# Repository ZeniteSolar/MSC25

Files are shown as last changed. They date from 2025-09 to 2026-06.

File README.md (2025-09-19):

# Módulo Sensor de Corrente(MSC25)

## Visão Geral

Este projeto consiste em uma placa de circuito impresso (PCB) com firmware embarcado, projetada para realizar a leitura de alta precisão de um sensor de corrente de efeito Hall e transmitir os dados através do barramento CAN.

O firmware foi desenvolvido em C para microcontroladores AVR, seguindo uma arquitetura modular, não-bloqueante e orientada por eventos, garantindo robustez e tempo de resposta previsível. O sistema é configurado e compilado utilizando um ambiente `avr-gcc` e `make`.

## Principais Características

* **Microcontrolador:** ATmega328P operando a 16MHz.
* **Comunicação:** Interface CAN Bus 2.0A (11-bit) implementada com controlador dedicado MCP2515 e transceptor MCP2561.
* **Leitura de Sensor:** Interface analógica de alta precisão para sensores de corrente, com condicionamento de sinal.
* **Fonte de Alimentação:** Sistema de alimentação robusto com fonte simétrica isolada para o estágio analógico.
* **Modos de Leitura:** Firmware com modos de operação configuráveis em tempo de compilação:
    * **Modo Média Móvel:** Fornece leituras estáveis, ideal para monitoramento de estado.
    * **Modo Instantâneo:** Fornece a última leitura bruta, ideal para captura de picos e transientes de corrente.
* **Arquitetura de Firmware:** Modular, baseada em máquina de estados e interrupções de hardware para tarefas periódicas.

## Detalhes do Hardware

O hardware foi projetado para garantir a integridade do sinal e a robustez da comunicação.

### Fonte de Alimentação

A placa recebe uma tensão de entrada de 18V, que é regulada internamente para os domínios digitais e analógicos:

* **+12V:** Gerado por um regulador LM7812 para alimentar periféricos e o estágio de amplificação.
* **+5V:** Gerado por um regulador LM7805 para alimentar o microcontrolador ATmega328P e o controlador CAN MCP2515.

#### Fonte Simétrica Isolada (±15V)

Para a correta polarização do sensor de corrente e do circuito de condicionamento analógico, foi implementada uma fonte simétrica de ±15V. Esta etapa utiliza dois conversores DC/DC isolados do tipo **PDSE1-S5-S15-S**. A partir da entrada de +5V, cada conversor gera uma tensão de saída isolada (+15V e -15V, respectivamente). A isolação galvânica garante que ruídos do barramento de alimentação principal não interfiram na precisão das medições analógicas.

### Sensor e Condicionamento de Sinal

O circuito foi projetado para interfacear com um sensor de corrente de efeito Hall, como o **SECOHR 200SCV**.

O sinal de saída do sensor é processado por um circuito de condicionamento baseado no amplificador operacional **LM324**. Este estágio tem a função de amplificar e deslocar o nível de tensão (offset) do sinal, ajustando-o para a faixa de leitura do conversor Analógico-Digital (ADC) do ATmega328P (0-5V). O resultado é um sinal robusto e centralizado, que permite a medição de correntes tanto positivas quanto negativas.

## Detalhes do Firmware

O firmware é escrito em C puro (padrão gnu99) e compilado com `avr-gcc`.

### Arquitetura

A lógica principal é controlada por uma máquina de estados (`machine.c`) que é executada em uma frequência fixa de 100 Hz, controlada pela interrupção do `Timer2`. A leitura do ADC é desacoplada da lógica principal, sendo disparada pelo `Timer0` a uma frequência de 1000 Hz e processada através de interrupções (`ISR(ADC_vect)`), garantindo que as amostragens ocorram de forma consistente. A comunicação entre a rotina de interrupção e o laço principal é feita através de flags voláteis para evitar condições de corrida.

### Módulos Principais

* **`main`**: Ponto de entrada, inicialização dos periféricos e laço principal.
* **`adc`**: Gerencia a configuração do ADC, o disparo por timer, a rotina de interrupção e as funções de processamento (média e leitura instantânea). Inclui um placeholder para **linearização** do sensor.
* **`machine`**: Contém a máquina de estados principal e a lógica de aplicação.
* **`can_app`**: Camada de aplicação do protocolo CAN. Responsável por montar e enviar as mensagens nos intervalos corretos.
* **`conf`**: Arquivo de cabeçalho central para todas as configurações de compilação, como ativação de módulos e seleção de modos de operação.

## Protocolo CAN

A placa se identifica na rede CAN e transmite duas mensagens principais.

* **Nome do Módulo:** `MSC25_1`
* **Assinatura (Signature):** `195` (0xC3)

| Mensagem | ID (Hex) | ID (Dec) | Frequência | Tamanho | Payload |
| :--- | :---: | :---: | :---: | :---: | :--- |
| **State** | `0x79` | 121 | 1 Hz | 3 Bytes | `[Assinatura, Estado, Erro]` |
| **Measurements** | `0xF0` | 240 | 10 Hz | 3 Bytes | `[Assinatura, Corrente_L, Corrente_H]` |

## Ambiente de Desenvolvimento

* **Toolchain:** `avr-gcc`, `avr-libc`, `make`
* **Programador:** `avrdude` (configurado para `arduino`)
* **Biblioteca Principal:** `avr-can-lib` (deve estar presente na pasta `lib/`)

## Como Compilar e Gravar

1.  **Preparar Bibliotecas:** Execute o script para compilar a `avr-can-lib` e baixar o `can_ids.h` mais recente.
    ```bash
    ./makelibs.sh
    ```

2.  **Compilar o Projeto:** Use o comando `make` para compilar todo o código-fonte.
    ```bash
    make
    ```

3.  **Limpar o Projeto:** Para apagar os arquivos compilados.
    ```bash
    make clean
    ```

4.  **Gravar na Placa:** Para compilar (se necessário) e gravar o firmware no microcontrolador.
    ```bash
    make flash
    ```
5.  **Fazer Tudo (Limpar, Compilar, Gravar e Monitorar):**
    ```bash
    ./up.sh
    ```

 ## Precisa adicionar ao can_ids.h
  ```
 // MSC25_1 - Módulo Sensor de Corrente (Sua Nova Placa)
#define CAN_SIGNATURE_MSC25_1 195
// MSC25_1 - STATE - Module state report
#define CAN_MSG_MSC25_1_STATE_ID 121
#define CAN_MSG_MSC25_1_STATE_LENGTH 3
#define CAN_MSG_MSC25_1_STATE_FREQUENCY 1
#define CAN_MSG_MSC25_1_STATE_SIGNATURE_BYTE 0 //<!" Senders signature
#define CAN_MSG_MSC25_1_STATE_STATE_BYTE 1     //<!" State code
#define CAN_MSG_MSC25_1_STATE_ERROR_BYTE 2     //<!" Error code

// MSC25_1 - MEASUREMENTS - Current measurements from the sensor
#define CAN_MSG_MSC25_1_MEASUREMENTS_ID 240
#define CAN_MSG_MSC25_1_MEASUREMENTS_LENGTH 3
#define CAN_MSG_MSC25_1_MEASUREMENTS_FREQUENCY 10
#define CAN_MSG_MSC25_1_MEASUREMENTS_SIGNATURE_BYTE 0    //<!" Senders signature
#define CAN_MSG_MSC25_1_MEASUREMENTS_CURRENT_L_BYTE 1    //<!" Average current, byte low
#define CAN_MSG_MSC25_1_MEASUREMENTS_CURRENT_H_BYTE 2    //<!" Average current, byte high
```

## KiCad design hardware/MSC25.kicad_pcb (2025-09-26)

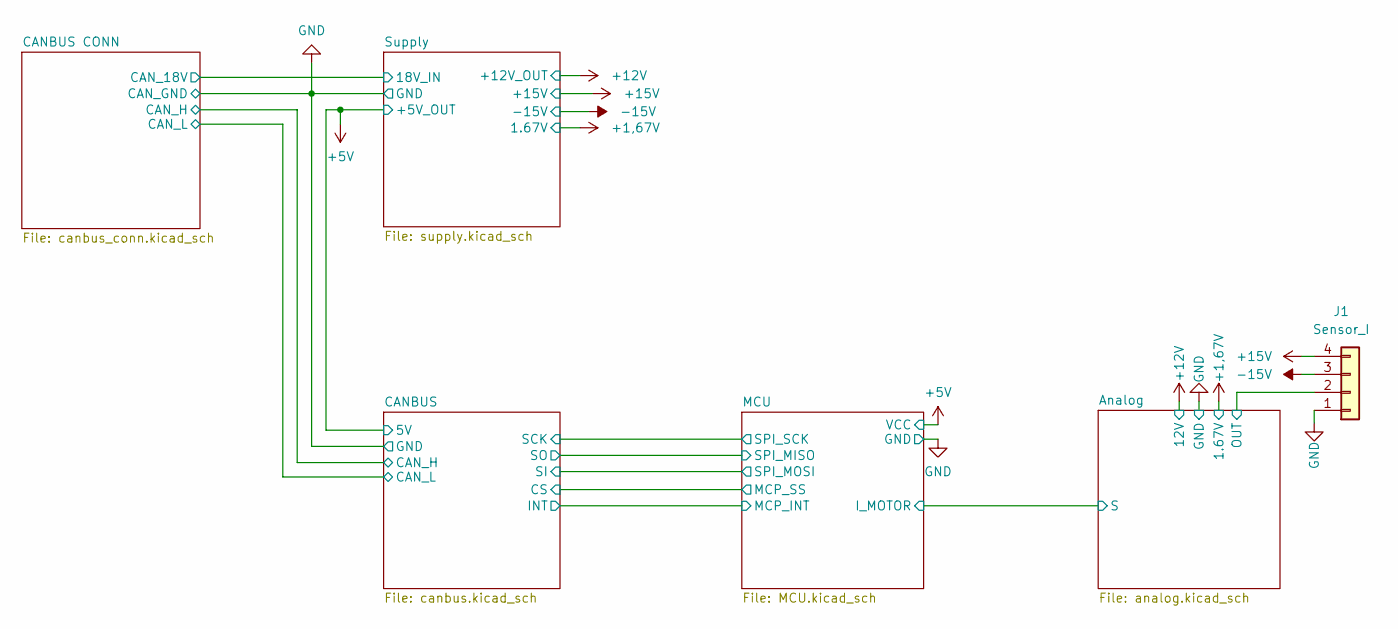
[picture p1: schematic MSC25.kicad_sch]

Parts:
J1: Sensor_I; PinHeader_1x04_P2.54mm_Vertical

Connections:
+15V: J1.4; also elsewhere on the board
-15V: J1.3; also elsewhere on the board
/Analog/OUT: J1.2; also elsewhere on the board
GND: J1.1; also elsewhere on the board

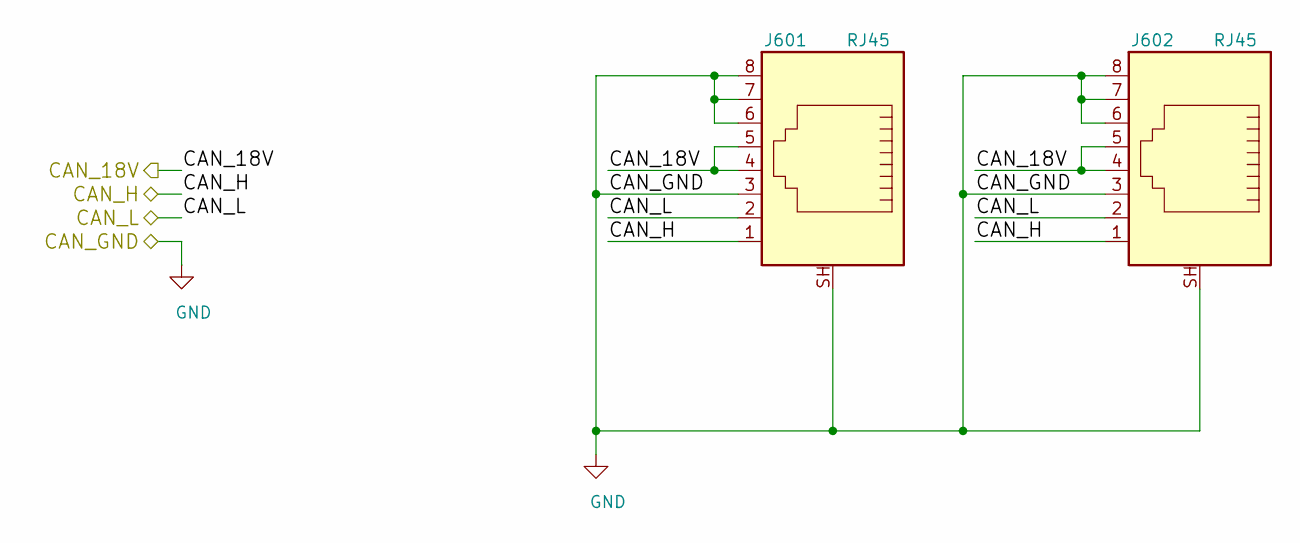
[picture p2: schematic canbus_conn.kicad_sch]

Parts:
J601, J602: RJ45; RJ45_YH59_01

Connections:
/CANBUS CONN/CAN_18V: J601.4, J601.5, J602.4, J602.5; also elsewhere on the board
/CANBUS CONN/CAN_H: J601.1, J602.1; also elsewhere on the board
/CANBUS CONN/CAN_L: J601.2, J602.2; also elsewhere on the board
GND: J601.3, J601.6, J601.7, J601.8, J601.SH, J602.3, J602.6, J602.7, J602.8, J602.SH; also elsewhere on the board

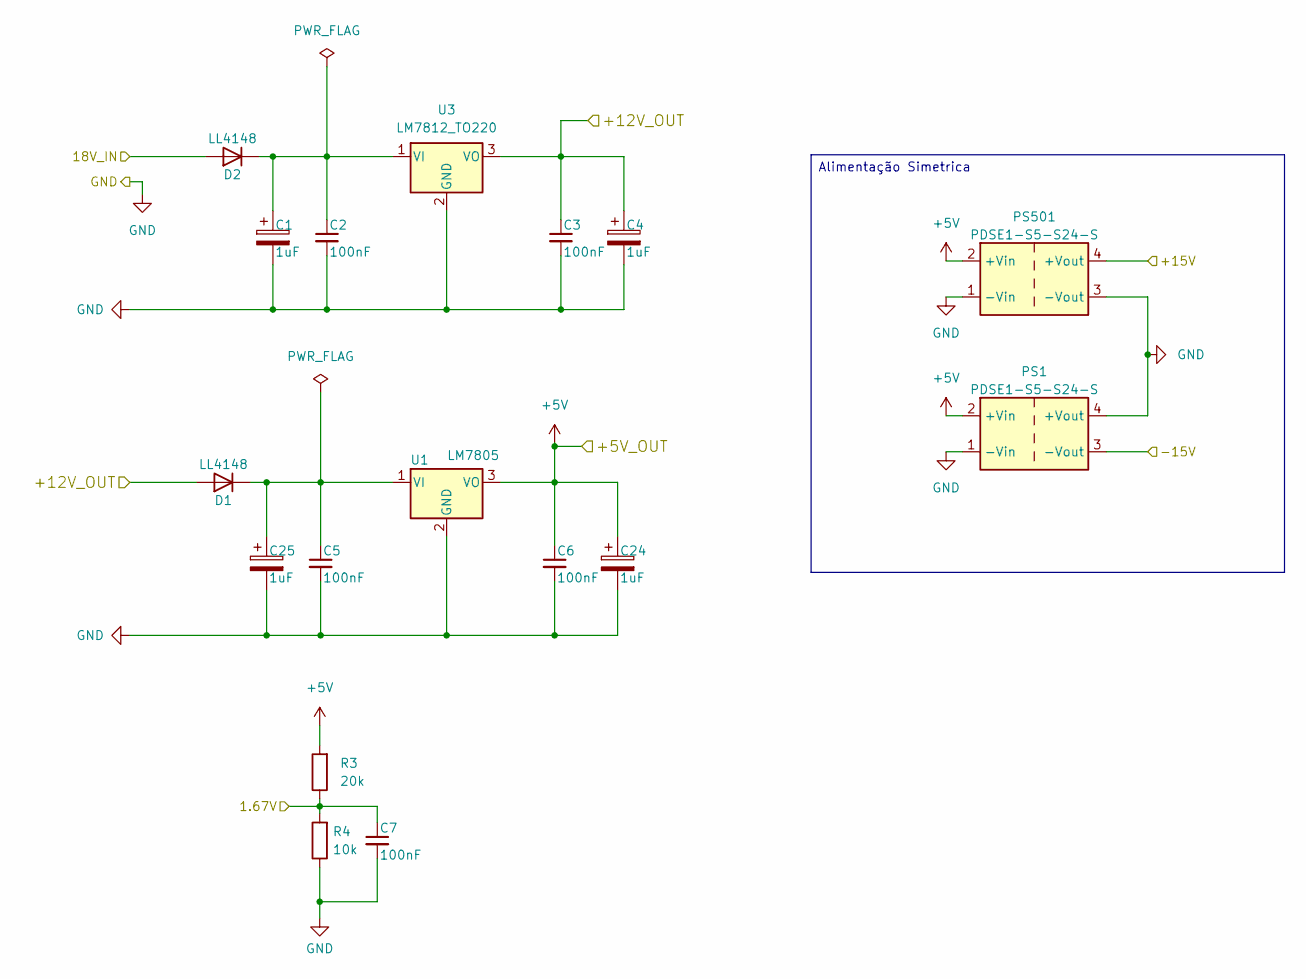
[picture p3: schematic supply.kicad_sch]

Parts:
C1, C4, C24, C25: 1uF; CP_EIA-6032-15_Kemet-U_HandSolder
C2, C3, C5, C6, C7: 100nF; C_0805_2012Metric_Pad1.18x1.45mm_HandSolder
D1, D2: LL4148; D_MiniMELF_Handsoldering
PS1, PS501: PDSE1-S5-S24-S; Converter_DCDC_Murata_MEE3SxxxxSC_THT
R3: 20k; R_0805_2012Metric_Pad1.20x1.40mm_HandSolder
R4: 10k; R_0805_2012Metric_Pad1.20x1.40mm_HandSolder
U1: LM7805; TO-220-3_Horizontal_TabDown
U3: LM7812_TO220; TO-220-3_Horizontal_TabDown

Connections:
+1,67V: C7.1, R3.1, R4.2; also elsewhere on the board
+5V: C6.1, C24.1, PS1.2 (+Vin), PS501.2 (+Vin), R3.2, U1.3 (VO); also elsewhere on the board
+12V: C3.1, C4.1, D1.2 (A), U3.3 (VO); also elsewhere on the board
+15V: PS501.4 (+Vout); also elsewhere on the board
-15V: PS1.3 (-Vout); also elsewhere on the board
/CANBUS CONN/CAN_18V: D2.2 (A); also elsewhere on the board
GND: C1.2, C2.2, C3.2, C4.2, C5.2, C6.2, C7.2, C24.2, C25.2, PS1.1 (-Vin), PS1.4 (+Vout), PS501.1 (-Vin), PS501.3 (-Vout), R4.1, U1.2 (GND), U3.2 (GND); also elsewhere on the board
unnamed: C5.1, C25.1, D1.1 (K), U1.1 (VI)
unnamed: C1.1, C2.1, D2.1 (K), U3.1 (VI)

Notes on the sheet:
Alimentação Simetrica

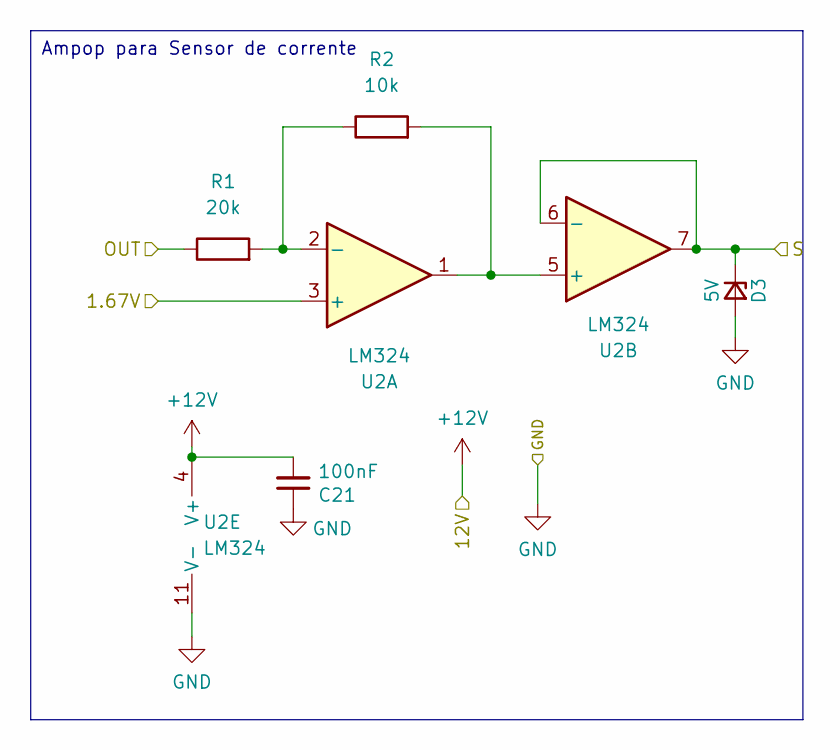
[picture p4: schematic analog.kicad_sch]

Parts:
C21: 100nF; C_0805_2012Metric_Pad1.18x1.45mm_HandSolder
D3: 5V; D_MiniMELF
R1: 20k; R_0805_2012Metric_Pad1.20x1.40mm_HandSolder
R2: 10k; R_0805_2012Metric_Pad1.20x1.40mm_HandSolder
U2: LM324

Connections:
+1,67V: U2.3 (+); also elsewhere on the board
+12V: C21.2, U2.4 (V+); also elsewhere on the board
/Analog/OUT: R1.1; also elsewhere on the board
/Analog/S: D3.1 (K), U2.6 (-), U2.7; also elsewhere on the board
GND: C21.1, D3.2 (A), U2.11 (V-); also elsewhere on the board
unnamed: R1.2, R2.1, U2.2 (-)
unnamed: R2.2, U2.1, U2.5 (+)

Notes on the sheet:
Ampop para Sensor de corrente

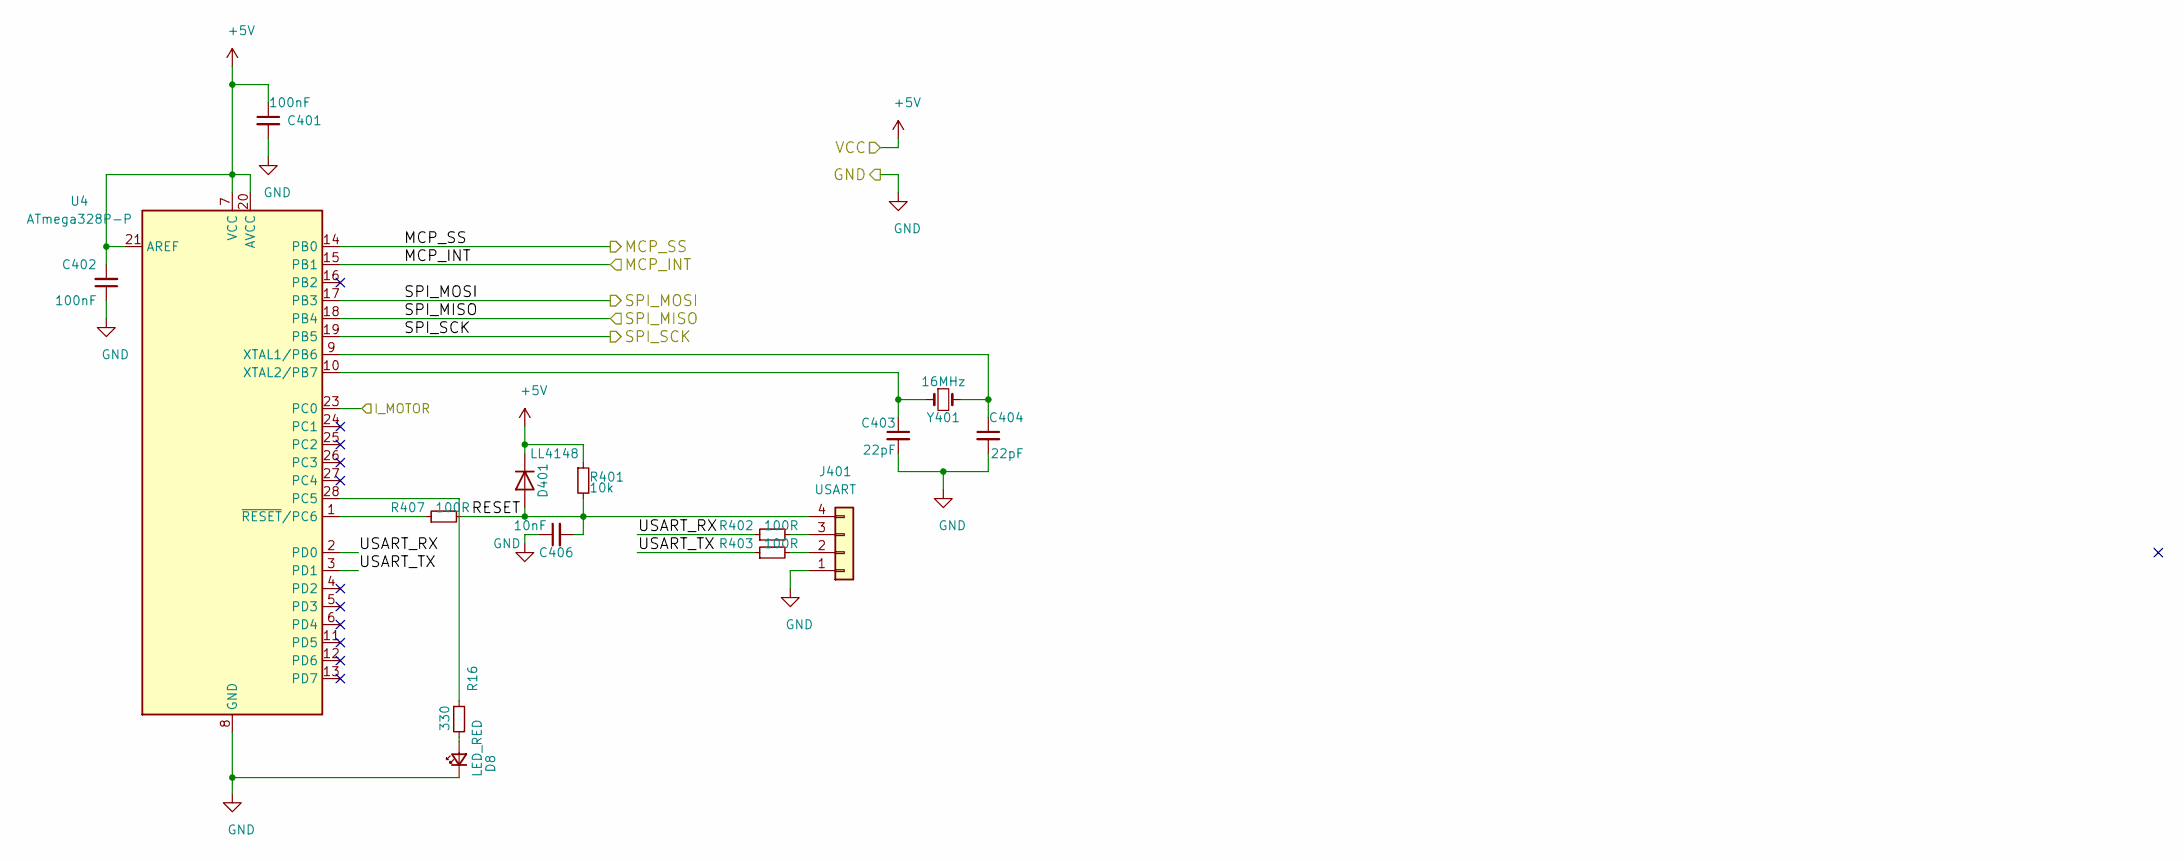
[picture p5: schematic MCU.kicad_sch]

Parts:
C401, C402: 100nF; C_0805_2012Metric_Pad1.18x1.45mm_HandSolder
C403, C404: 22pF; C_0805_2012Metric_Pad1.18x1.45mm_HandSolder
C406: 10nF; C_0805_2012Metric_Pad1.18x1.45mm_HandSolder
D8: LED_RED; LED_0805_2012Metric_Pad1.15x1.40mm_HandSolder
D401: LL4148; D_MiniMELF_Handsoldering
J401: USART; PinHeader_1x04_P2.54mm_Vertical
R16: 330; R_0805_2012Metric_Pad1.20x1.40mm_HandSolder
R401: 10k; R_0805_2012Metric_Pad1.20x1.40mm_HandSolder
R402, R403, R407: 100R; R_0805_2012Metric_Pad1.20x1.40mm_HandSolder
U4: ATmega328P-P; DIP-28_W7.62mm_LongPads
Y401: 16MHz; Crystal_HC49-U_Vertical

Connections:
+5V: C401.1, C402.2, D401.1 (K), R401.1, U4.7 (VCC), U4.20 (AVCC), U4.21 (AREF); also elsewhere on the board
/Analog/S: U4.23 (PC0); also elsewhere on the board
/MCU/MCP_INT: U4.15 (PB1); also elsewhere on the board
/MCU/MCP_SS: U4.14 (PB0); also elsewhere on the board
/MCU/RESET: C406.2, D401.2 (A), J401.4, R401.2, R407.2
/MCU/SPI_MISO: U4.18 (PB4); also elsewhere on the board
/MCU/SPI_MOSI: U4.17 (PB3); also elsewhere on the board
/MCU/SPI_SCK: U4.19 (PB5); also elsewhere on the board
/MCU/USART_RX: R402.1, U4.2 (PD0)
/MCU/USART_TX: R403.1, U4.3 (PD1)
GND: C401.2, C402.1, C403.2, C404.2, C406.1, D8.1 (K), J401.1, U4.8 (GND), U4.22 (GND); also elsewhere on the board
unnamed: D8.2 (A), R16.2
unnamed: J401.2, R403.2
unnamed: J401.3, R402.2
unnamed: R16.1, U4.28 (PC5)
unnamed: C404.1, U4.9 (XTAL1/PB6), Y401.2
unnamed: C403.1, U4.10 (XTAL2/PB7), Y401.1
unnamed: R407.1, U4.1 (~RESET/PC6)

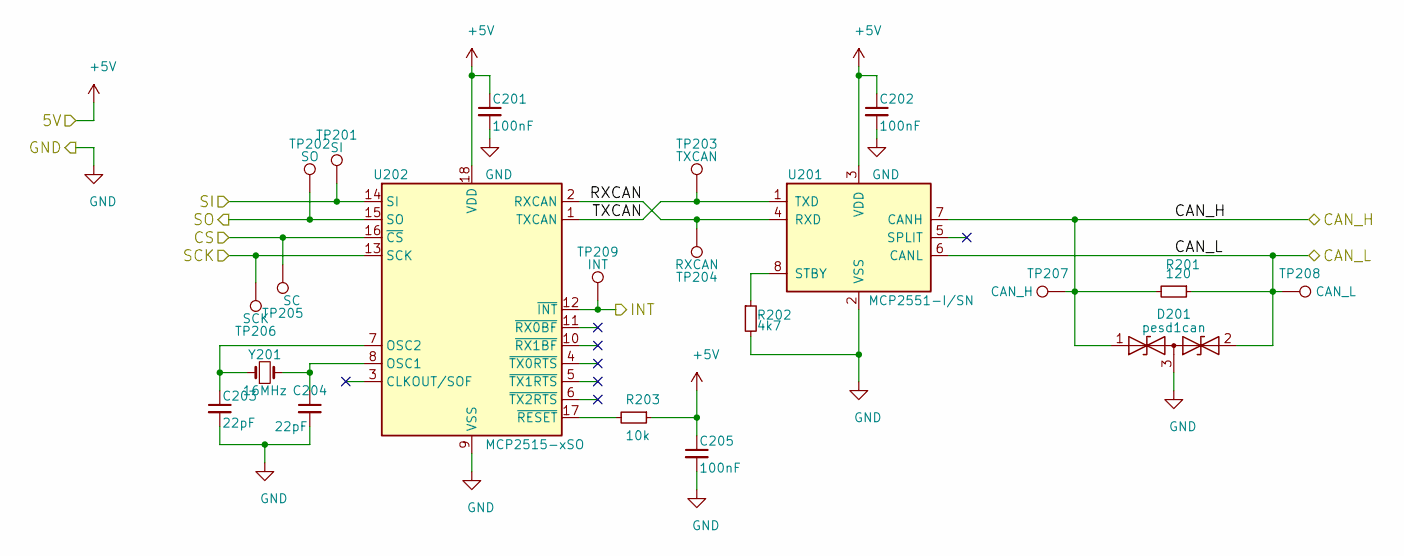
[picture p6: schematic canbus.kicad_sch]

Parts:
C201, C202, C205: 100nF; C_0805_2012Metric_Pad1.18x1.45mm_HandSolder
C203, C204: 22pF; C_0805_2012Metric_Pad1.18x1.45mm_HandSolder
D201: pesd1can; SOT-23_Handsoldering
R201: 120; R_0805_2012Metric_Pad1.20x1.40mm_HandSolder
R202: 4k7; R_0805_2012Metric_Pad1.20x1.40mm_HandSolder
R203: 10k; R_0805_2012Metric_Pad1.20x1.40mm_HandSolder
TP201: SI; TestPoint_Pad_D1.5mm
TP202: SO; TestPoint_Pad_D1.5mm
TP203: TXCAN; TestPoint_Pad_D1.5mm
TP204: RXCAN; TestPoint_Pad_D1.5mm
TP205: SC; TestPoint_Pad_D1.5mm
TP206: SCK; TestPoint_Pad_D1.5mm
TP207: CAN_H; TestPoint_Pad_D1.5mm
TP208: CAN_L; TestPoint_Pad_D1.5mm
TP209: INT; TestPoint_Pad_D1.5mm
U201: MCP2551-I/SN; SOIC-8_3.9x4.9mm_P1.27mm
U202: MCP2515-xSO; SOIC-18W_7.5x11.6mm_P1.27mm
Y201: 16MHz; Crystal_HC49-U_Vertical

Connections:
+5V: C201.1, C202.1, C205.1, R203.1, U201.3 (VDD), U202.18 (VDD); also elsewhere on the board
/CANBUS CONN/CAN_H: D201.1 (A1), R201.2, TP207.1, U201.7 (CANH); also elsewhere on the board
/CANBUS CONN/CAN_L: D201.2 (A2), R201.1, TP208.1, U201.6 (CANL); also elsewhere on the board
/CANBUS/RXCAN: TP204.1, U201.4 (RXD), U202.2 (RXCAN)
/CANBUS/TXCAN: TP203.1, U201.1 (TXD), U202.1 (TXCAN)
/MCU/MCP_INT: TP209.1, U202.12 (~INT); also elsewhere on the board
/MCU/MCP_SS: TP205.1, U202.16 (~CS); also elsewhere on the board
/MCU/SPI_MISO: TP202.1, U202.15 (SO); also elsewhere on the board
/MCU/SPI_MOSI: TP201.1, U202.14 (SI); also elsewhere on the board
/MCU/SPI_SCK: TP206.1, U202.13 (SCK); also elsewhere on the board
GND: C201.2, C202.2, C203.2, C204.2, C205.2, D201.3 (common), R202.2, U201.2 (VSS), U202.9 (VSS); also elsewhere on the board
unnamed: R202.1, U201.8 (STBY)
unnamed: C204.1, U202.8 (OSC1), Y201.2
unnamed: C203.1, U202.7 (OSC2), Y201.1
unnamed: R203.2, U202.17 (~RESET)

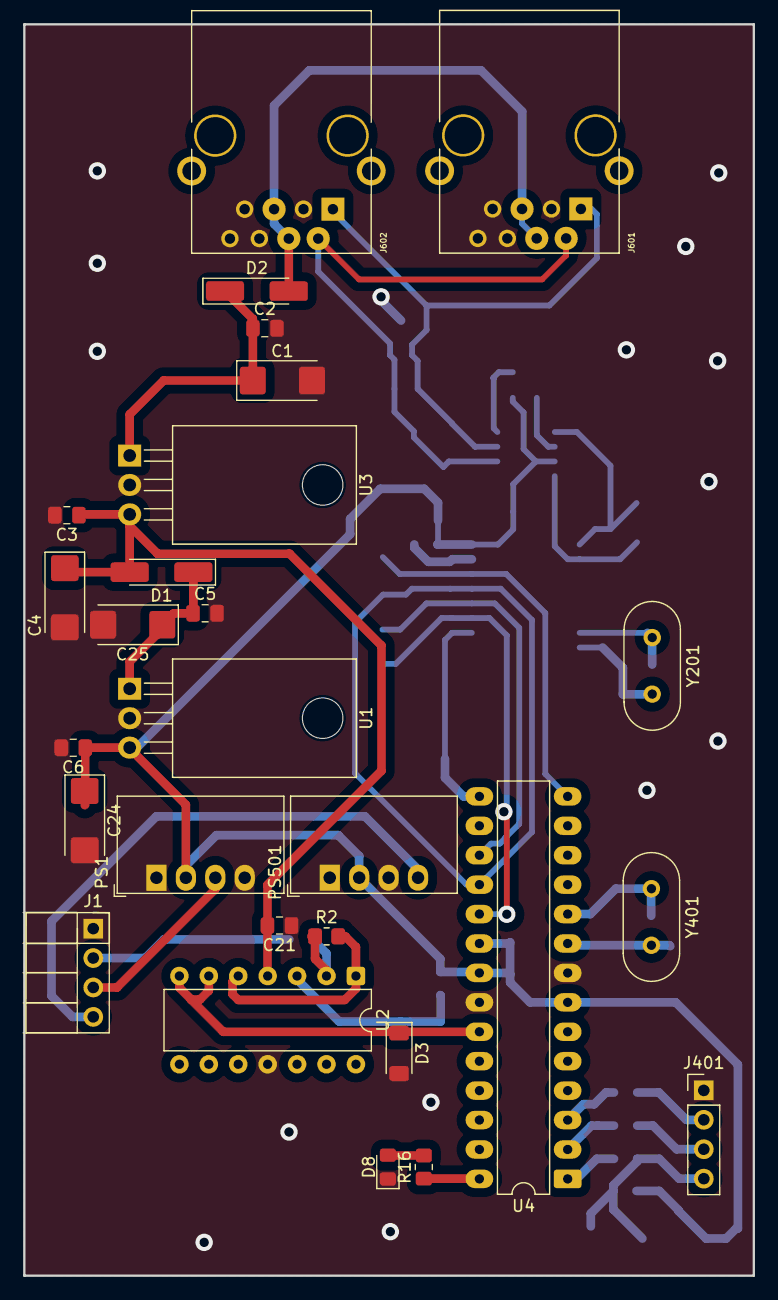
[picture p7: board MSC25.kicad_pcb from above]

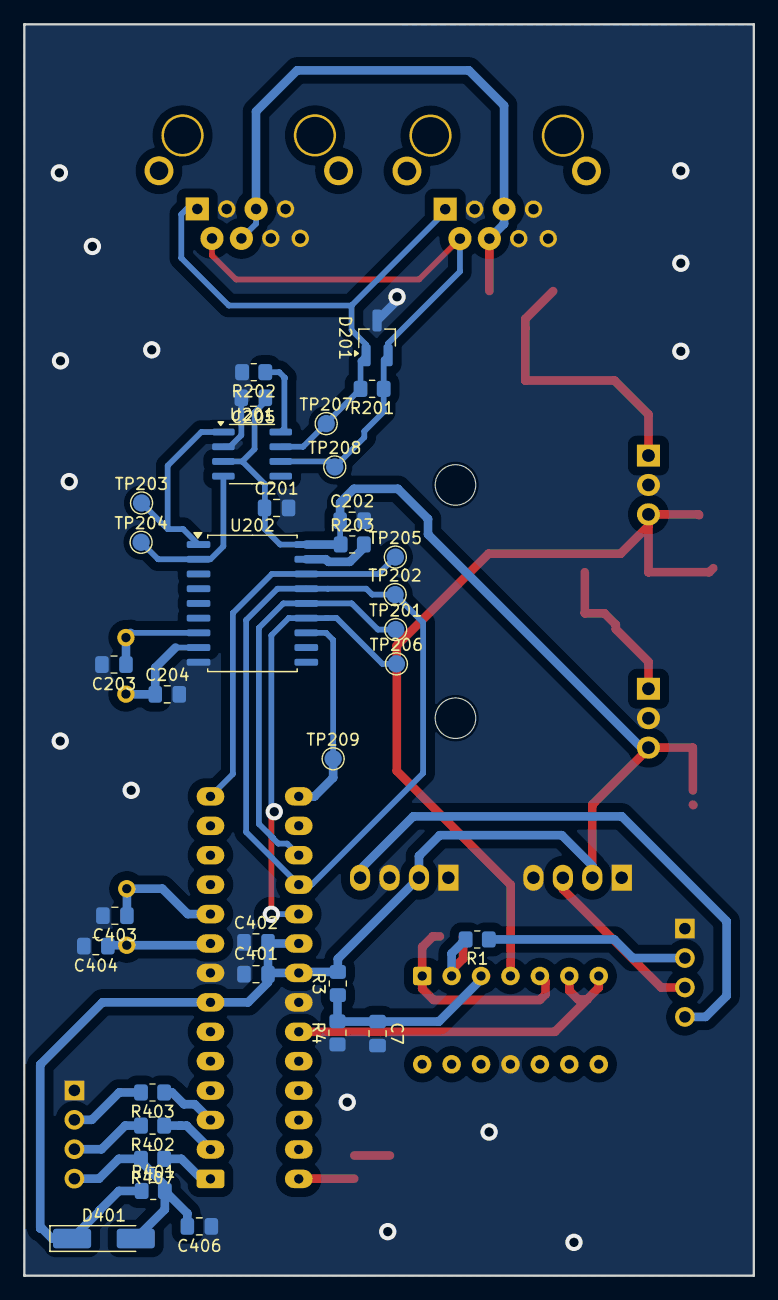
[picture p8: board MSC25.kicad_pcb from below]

Board: 2 copper layers, 63.0 x 108.0 mm, 61 parts (34 on the bottom side), 36 nets.

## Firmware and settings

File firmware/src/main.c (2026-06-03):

#include "main.h"

void init(void)
{
    // 1. Inicializa Serial
    #ifdef USART_ON
        usart_init();
        usart_send_string("\n\n--- MSC25_1 Firmware ---\n");
    #endif

    // 2. Teste rápido do LED na inicialização
    // Isso confirma visualmente que o pino PC5 está correto
    #ifdef LED_ON
        set_bit(LED_DDR, LED1); // Configura PC5 como saída
        
        // Pisca 3 vezes rápido
        for(int i=0; i<3; i++) {
            set_bit(LED_PORT, LED1); 
            for(volatile long j=0; j<100000; j++); // Delay simples
            clr_bit(LED_PORT, LED1);
            for(volatile long j=0; j<100000; j++);
        }
        VERBOSE_MSG_INIT(usart_send_string("LED Init... OK\n"));
    #endif

    #ifdef WATCHDOG_ON
        wdt_enable(WDTO_2S);
    #endif
    wdt_reset();

    #ifdef SPI_ON
        DDRB |= (1 << PB2) | (1 << PB3) | (1 << PB5);
        PORTB |= (1 << PB2);
        VERBOSE_MSG_INIT(usart_send_string("SPI... OK\n"));
    #endif

    #ifdef CAN_ON
        VERBOSE_MSG_INIT(usart_send_string("CAN... "));
        if (!can_init(BITRATE_500_KBPS)) {
            VERBOSE_MSG_INIT(usart_send_string("FALHA (Sem ACK)\n"));
        } else {
            VERBOSE_MSG_INIT(usart_send_string("OK\n"));
        }
    #endif

    #ifdef ADC_ON
        adc_init();
        VERBOSE_MSG_INIT(usart_send_string("ADC... OK\n"));
    #endif
    
 	#ifdef MACHINE_ON
		machine_init();
	#endif

    sei(); // Habilita interrupções
    usart_send_string("Sistema Iniciado.\n");
}

int main(void)
{
    init();

	for(;;)
    {
		#ifdef WATCHDOG_ON
            wdt_reset();
		#endif

        #ifdef MACHINE_ON
            machine_run();
        #endif
	}
}

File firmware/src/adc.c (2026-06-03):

#include "adc.h"
#include "conf.h"
#include "usart.h"
#include <avr/interrupt.h>
#include "bit_utils.h"

volatile uint8_t adc_data_ready = 0;
volatile adc_cbuf_t cbuf_adc0;
volatile uint16_t adc_last_instant_value = 0; 

// --- CALIBRAÇÃO FINAL ---
#define ADC_OFFSET_UNIT  504    // Zero Amperes (Mantido)
#define ADC_FACTOR       48     // RECALCULADO: De 43 para 51 (Ajuste para 3.05A)

void adc_init(void)
{
    CBUF_Init(cbuf_adc0);
    DIDR0 |= (1 << ADC0D); 
    ADMUX = (1 << REFS0); 
    ADCSRA = (1 << ADEN) | (1 << ADATE) | (1 << ADIE) | (1 << ADPS2) | (1 << ADPS1) | (1 << ADPS0);
    ADCSRB = 0; 
    ADCSRA |= (1 << ADSC);
}

// FUNÇÃO DE SOBREAMOSTRAGEM (ALTA RESOLUÇÃO)
uint16_t ma_adc0(void)
{
    uint32_t sum_raw = 0;
    
    // 1. Soma 64 amostras
    for (uint8_t i = 0; i < ADC_AVG_BUFFER_SIZE; i++) {
        sum_raw += cbuf_adc0.m_entry[i];
    }
    
    // 2. Offset total de 64 amostras
    uint32_t offset_total = (uint32_t)ADC_OFFSET_UNIT * ADC_AVG_BUFFER_SIZE;
    
    int32_t diff_total;
    
    // 3. Diferença acumulada
    if (sum_raw > offset_total) {
        diff_total = (int32_t)(sum_raw - offset_total);
    } else {
        diff_total = (int32_t)(offset_total - sum_raw);
    }

    // 4. Aplica novo fator (51)
    uint32_t current_calibrated = (uint32_t)((diff_total * ADC_FACTOR) >> ADC_AVG_BUFFER_SIZE_LOG2);

    return (uint16_t)current_calibrated;
}

uint16_t get_last_adc_linearized(void)
{
    uint16_t x_raw = adc_last_instant_value;
    int32_t val;
    if (x_raw > ADC_OFFSET_UNIT) val = (x_raw - ADC_OFFSET_UNIT) * ADC_FACTOR;
    else val = (ADC_OFFSET_UNIT - x_raw) * ADC_FACTOR;
    return (uint16_t)val;
}

ISR(ADC_vect)
{
    uint16_t current_reading = ADC;
    adc_last_instant_value = current_reading; 
    CBUF_Push(cbuf_adc0, current_reading);   
    adc_data_ready = 1; 
}

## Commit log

2025-09-19 adicionando arquivos
    [MCU.kicad_sch, MSC25.kicad_pcb, MSC25.kicad_sch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]
2025-09-20 Remove Zone.Identifier and kicad backups
2025-09-20 Added -backups to ignore new kicad version backups
2025-09-26 adicionando gerbers e atualização
    [MSC25-B_Cu.gbr, MSC25-B_Mask.gbr, MSC25-B_Paste.gbr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]
2025-09-26 atualizações
    [MCU.kicad_sch, MSC25.kicad_pcb, MSC25.kicad_sch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]
